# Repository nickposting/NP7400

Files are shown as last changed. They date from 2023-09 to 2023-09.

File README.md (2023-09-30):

# NP7400  

## Processor Card

### Docs
[g4pinout.pdf](/docs/g4pinout.pdf) contains the pinout of the connector used on
Power Mac G4 computers. Some important notes regarding the pinout:

* Pin assignments were determined by first sanding/filing down the processor
card (8 layers) from a 667MHz Digital Audio G4, and then using the card from
a 400MHz AGP Graphics G4, intact, albeit with the processor desoldered,
to verify that all the connections were correct.
* None of the cards involved in this process were dual-processor cards, so any
assignments unique to dual-processor systems, if any exist, have not been 
recorded.
* As written, the pin assignments are representative of how an MPC7450-series
MPU would be interfaced to the Power Mac motherboard -- for instance, only address
bits A4-A35 are present on the connector. Unlike earlier G4 processors, the 7450
features an extended 36-bit address bus, however, the four most significant bits
(A0-A3) are not used in Power Mac systems. Bearing in mind that PowerPC datasheet
conventions specify bit zero as the most-significant bit, a processor card design
featuring an earlier 7400/7410 MPU with a 32-bit address bus would need to have the
MPU's bit A31 connected to the pin labelled "A35" on the pinout, A30 connected to
"A34," and so on. The same applies to the DTI (Data Transaction Index) signals, of
which there are less on MPUs predating the 7450.

Regarding pins marked "special":
* Pins marked "R" are connected only to resistor straps, most of which go to ground.
I am still trying to understand the purpose of most of these. Some straps are
unpopulated on every board in my possession, whereas others vary between boards.
* SDA and SCL are connected only to the SPD I<sup>2</sup>C EEPROM on every board.
* Pins B2 and K30 are connected only to each other on every board. I assume this is
intended for the motherboard to sense whether or not the processor card is fully
seated.
* CKSTP# on the connector is directly connected to both CKSTP_IN# and CKSTP_OUT# on
the MPU.
* D63 is pulled to ground by a 1kΩ resistor on every board for some reason.
* The length of the SYSCLK track in particular is critical (tangentially, it appears
that on cards built for Power Macs with a 167MHz FSB, most track lengths become
tightly controlled).

## VRM

### Docs
[820-1152-A.pdf](/docs/820-1152-A.pdf) contains a poor schematic of the
original VRM board in the Power Mac G4 Cube, drawn only to verify whether or not
there was anything "unusual" about the OEM design (for all intents and purposes,
there isn't).
[np7400_VRM.pdf](/docs/np7400_VRM.pdf) contains the KiCad schematic of the
upgraded VRM board in PDF.

### Schematic and Board Layout
Schematic/layout files are provided as a complete KiCad project. As of the time
of this writing, schematic has been somewhat revised and does not reflect the
older revision of the layout included.

The newer schematic has not been thouroughly proofread. The older layout has not
been tested extensively and should not be used; there is considerable room for
improvement. Most planned changes are regarding optimization of routing, and ease
of assembly.

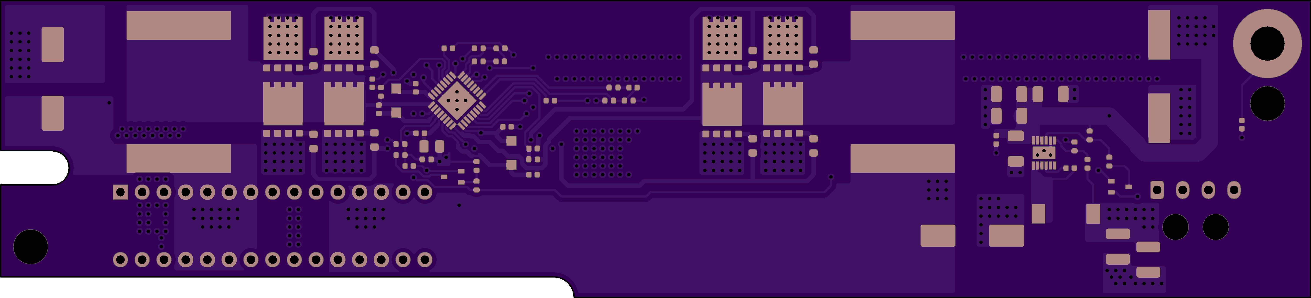
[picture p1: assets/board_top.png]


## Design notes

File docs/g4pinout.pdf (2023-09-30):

R | R-R | R | | DTI1 | QACK# | TA# | PMON_ IN# | DTI3 | TBEN | BG# | QREQ# | TEA# | | DBG# | | D59 | | D55 | | D58 | | | | | | R | | R
+12V | SNS | R | HRESET# | | GBL# | | A7 | | A25 | | A9 | | A17 | | A34 | | A35 | | D56 | | D38 | | D57
SRESET# | SMI# | R | | CI# | | A5 | | A18 | | A26 | | A31 | | A19 | | AACK# | | D60 | | D40 | | D63 | | D29 | | D25 | | D14
FAN1 | CKSTP# | | TSIZ0 | | HIT# | | WT# | | A27 | | A15 | | A30 | | A33 | | A29 | | D33 | | D62 | | D61 | | D24 | | D27 | | D23
INT# | | TSIZ1 | | TT0 | | DTI0 | | A11 | | A22 | | A23 | | A21 | | D34 | | D36 | | D30 | | D28 | | D22 | | D16 | | D10
TDI | TMS | | TBST | | TSIZ2 | | TT1 | | A16 | | A20 | | DTI2 | | D32 | | D35 | | D31 | | D26 | | D21 | | D19 | | D20 | | D15
FAN2 | TRST | | | TT3 | | BR# | | A24 | | A32 | | D37 | | D39 | | D9 | | D13 | | D3 | | D0 | | D17 | | D54 | | D50
| TCK | | | | TT2 | | | | A13 | | A28 | | ARTRY# | | D42 | | D11 | | D41 | | D44 | | D53 | | D5 | | D18 | | D12
| | TDO | | A8 | | A12 | | | | TT4 | | TS | | D8 | | D45 | | D51 | | D46 | | D43 | | D6 | | D49 | | D4 | SDA
| A4 | | A10 | | A14 | | A6 | | SYSCLK | | DRDY# | | D7 | | | | | | D48 | | D47 | | D52 | | D2 | | D1 | SCL | SNS

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
1 | 2 | 3 | 4 | 5 | 6 | 7 | 8 | 9 | 10 | 11 | 12 | 13 | 14 | 15 | 16 | 17 | 18 | 19 | 20 | 21 | 22 | 23 | 24 | 25 | 26 | 27 | 28 | 29 | 30
MPX Bus | GND | +5V | +3V3 | OVdd | Special | No Connect | https://github.com/nickposting/NP7400/

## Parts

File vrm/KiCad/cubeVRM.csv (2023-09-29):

Reference | Quantity | Value | Footprint | Datasheet | Arrow Part Number | Arrow Price/Stock | Description | Height | Manufacturer_Name | Manufacturer_Part_Number | Mouser Part Number | Mouser Price/Stock
C12 | 1 | 100pF | Capacitor_SMD:C_0402_1005Metric | ~
C16 C25 | 2 | 820pF | Capacitor_SMD:C_0402_1005Metric | ~
C18 C24 | 2 | 0.038uF | Capacitor_SMD:C_0402_1005Metric | ~
C2 | 1 | 680uF STANDARD | Capacitor_SMD:CP_Elec_16x17.5 | ~
C21 C23 | 2 | 6800pF | Capacitor_SMD:C_0402_1005Metric | ~
C9 C19 C22 C29 | 4 | 0.47uF | Capacitor_SMD:C_0402_1005Metric | ~
C26 C27 | 2 | 1000pF | Capacitor_SMD:C_0402_1005Metric | ~
C3 | 1 | 1nF | Capacitor_SMD:C_0402_1005Metric | ~
C32 C33 | 2 | 820uF | Capacitor_SMD:CP_Elec_10x10 | ~
C35 C36 C38 C39 C45 C46 | 6 | 22uF | Capacitor_SMD:C_1210_3225Metric | ~
C4 C6 C7 C8 C10 C11 C13 C15 C17 C20 C30 C31 C34 C37 C40 C43 | 16 | 2.2uF | Capacitor_SMD:C_1206_3216Metric | ~
C1 C5 C14 C28 C41 C42 | 6 | 1uF | Capacitor_SMD:C_0402_1005Metric | ~
C47 C50 | 2 | 0.1uF | Capacitor_SMD:C_0402_1005Metric | ~
C44 C48 C49 C51 | 4 | 10uF | Capacitor_SMD:C_1206_3216Metric | ~
D1 D2 | 2 | D_Schottky | Diode_SMD:D_SOD-123F | ~
F1 F2 | 2 | 4A | Fuse:Fuse_1206_3216Metric | ~
H1 H3 | 2 | MountingHole_NP | MountingHole:MountingHole_4mm | ~
H2 | 1 | MountingHole_Pad | MountingHole:MountingHole_4mm_Pad | ~
IC1 | 1 | LM25119QPSQ_NOPB | LM25119QPSQ_NOPB:QFN50P500X500X80-33N | http://www.ti.com/lit/gpn/lm25119q | LM25119QPSQ/NOPB | https://www.arrow.com/en/products/lm25119qpsqnopb/texas-instruments | Switching Controllers Automotive Grade 4.5-42V Wide Vin, Current Mode Dual Synchronous Buck Controller 32-WQFN -40 to 125 | 0.8 | Texas Instruments | LM25119QPSQ/NOPB | 595-LM25119QPSQ/NOPB | https://www.mouser.com/Search/Refine.aspx?Keyword=595-LM25119QPSQ%2FNOPB
IC2 | 1 | LMR51450FNDRRR | LMR51450FNDRRR:SON50P300X300X80-13N-D | https://www.ti.com/lit/ds/symlink/lmr51450.pdf?ts=1681907573404 | LMR51450FNDRRR | https://www.arrow.com/en/products/lmr51450fndrrr/texas-instruments?region=nac | Switching Voltage Regulators 36-V, 5-A synchronous buck converter | 0.8 | Texas Instruments | LMR51450FNDRRR | 595-LMR51450FNDRRR | https://www.mouser.co.uk/ProductDetail/Texas-Instruments/LMR51450FNDRRR?qs=rQFj71Wb1eVWWBj0Ni4OAA%3D%3D
J1 | 1 | Conn_01x04 | Connector_Molex:Molex_Micro-Fit_3.0_43650-0400_1x04_P3.00mm_Horizontal | ~
J2 | 1 | Conn_02x15_Odd_Even | Connector_PinHeader_2.54mm:PinHeader_2x15_P2.54mm_Vertical | ~
L1 | 1 | 8.2uH | SRP1770TA-5R6M:INDPM173169X700N | ~
L2 | 1 | 5.6uH | SRP1770TA-5R6M:INDPM173169X700N | ~
L3 | 1 | 6.8uH | Inductor_SMD:L_7.3x7.3_H4.5 | ~
Q1 Q10 | 2 | 2N3904 | Package_TO_SOT_SMD:SOT-323_SC-70 | https://www.onsemi.com/pub/Collateral/2N3903-D.PDF
Q2 Q3 Q4 Q5 Q6 Q7 Q8 Q9 | 8 | Q_NMOS_DGS | Package_SON:VSONP-8-1EP_5x6_P1.27mm | ~
R10 | 1 | 3.9R | Resistor_SMD:R_0805_2012Metric | ~
R11 | 1 | 24.9k | Resistor_SMD:R_0402_1005Metric | ~
R12 | 1 | 20.5k | Resistor_SMD:R_0402_1005Metric | ~
R13 R14 R15 R16 R24 R25 R26 R27 | 8 | 10R | Resistor_SMD:R_0603_1608Metric | ~
R17 | 1 | 3.92k | Resistor_SMD:R_0402_1005Metric | ~
R18 | 1 | 1.24k | Resistor_SMD:R_0402_1005Metric | ~
R19 | 1 | 84.5k | Resistor_SMD:R_0402_1005Metric | ~
R2 R30 R34 | 3 | 100R | Resistor_SMD:R_0402_1005Metric | ~
R20 R21 R28 R29 | 4 | 10R | Resistor_SMD:R_0402_1005Metric | ~
R22 R23 | 2 | 0R005 | Resistor_SMD:R_2512_6332Metric | ~
R3 | 1 | 47R | Resistor_SMD:R_0402_1005Metric | ~
R1 R31 R32 R35 | 4 | 100k | Resistor_SMD:R_0402_1005Metric | ~
R33 | 1 | 7.15k | Resistor_SMD:R_0402_1005Metric | ~
R4 | 1 | 52.3k | Resistor_SMD:R_0402_1005Metric | ~
R5 | 1 | 3k | Resistor_SMD:R_0402_1005Metric | ~
R6 | 1 | 5.76k | Resistor_SMD:R_0402_1005Metric | ~
R7 | 1 | 1.1k | Resistor_SMD:R_0402_1005Metric | ~
R8 | 1 | 124k | Resistor_SMD:R_0402_1005Metric | ~
R9 | 1 | 30k | Resistor_SMD:R_0402_1005Metric | ~

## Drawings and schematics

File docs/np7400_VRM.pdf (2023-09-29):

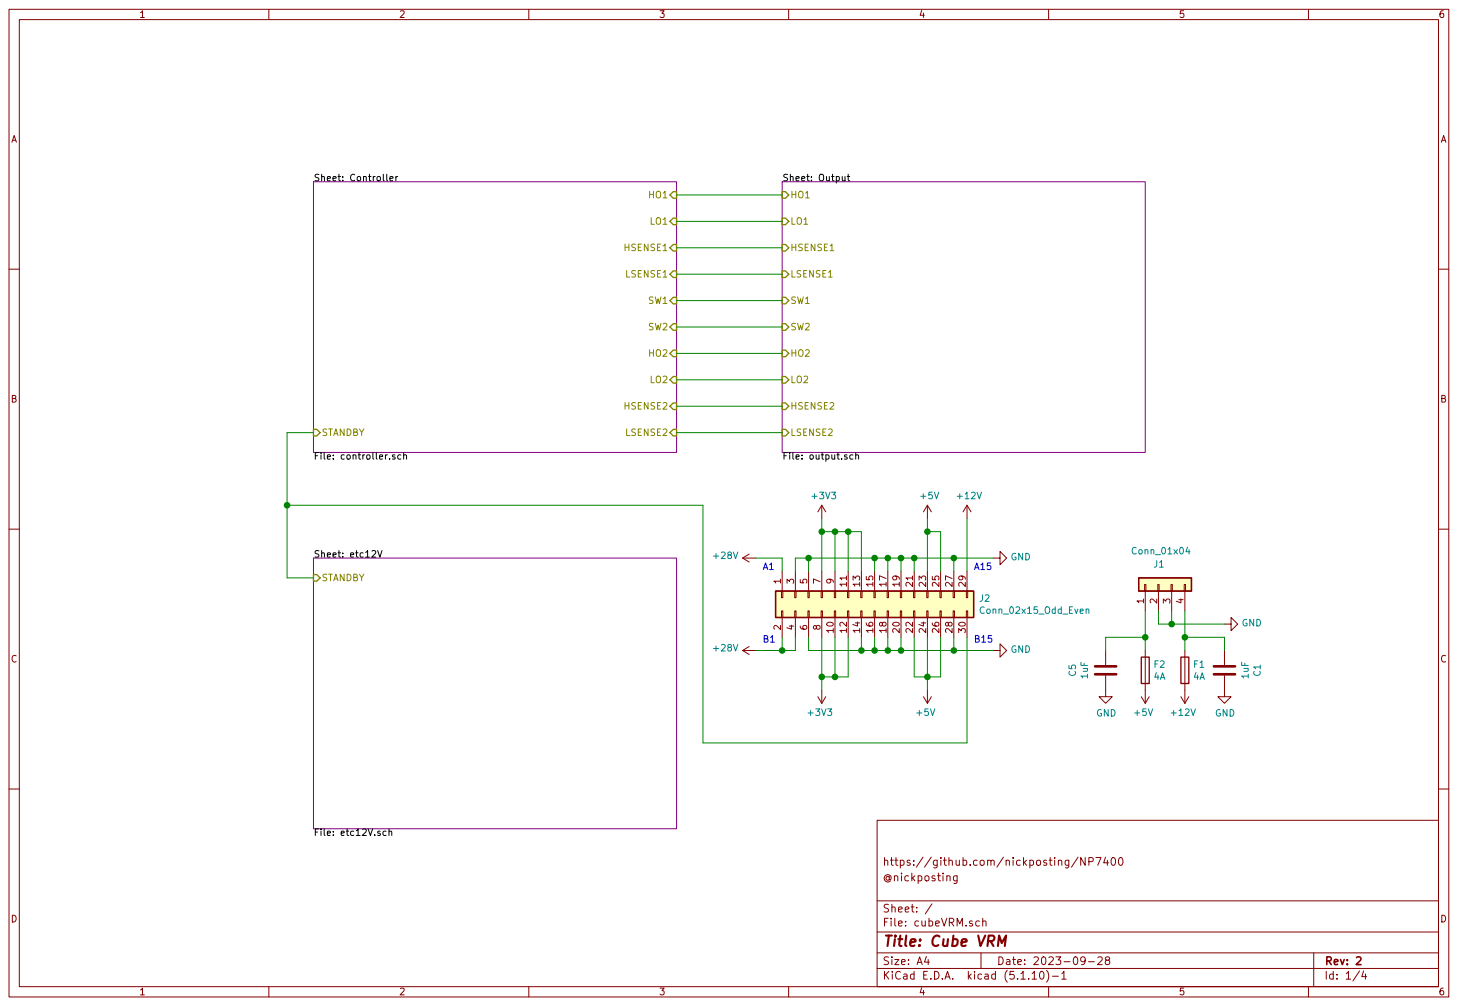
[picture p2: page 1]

https://github.com/nickposting/NP7400
File: cubeVRM.sch Sheet: / @nickposting

Id: 1/4 Title: Cube VRM

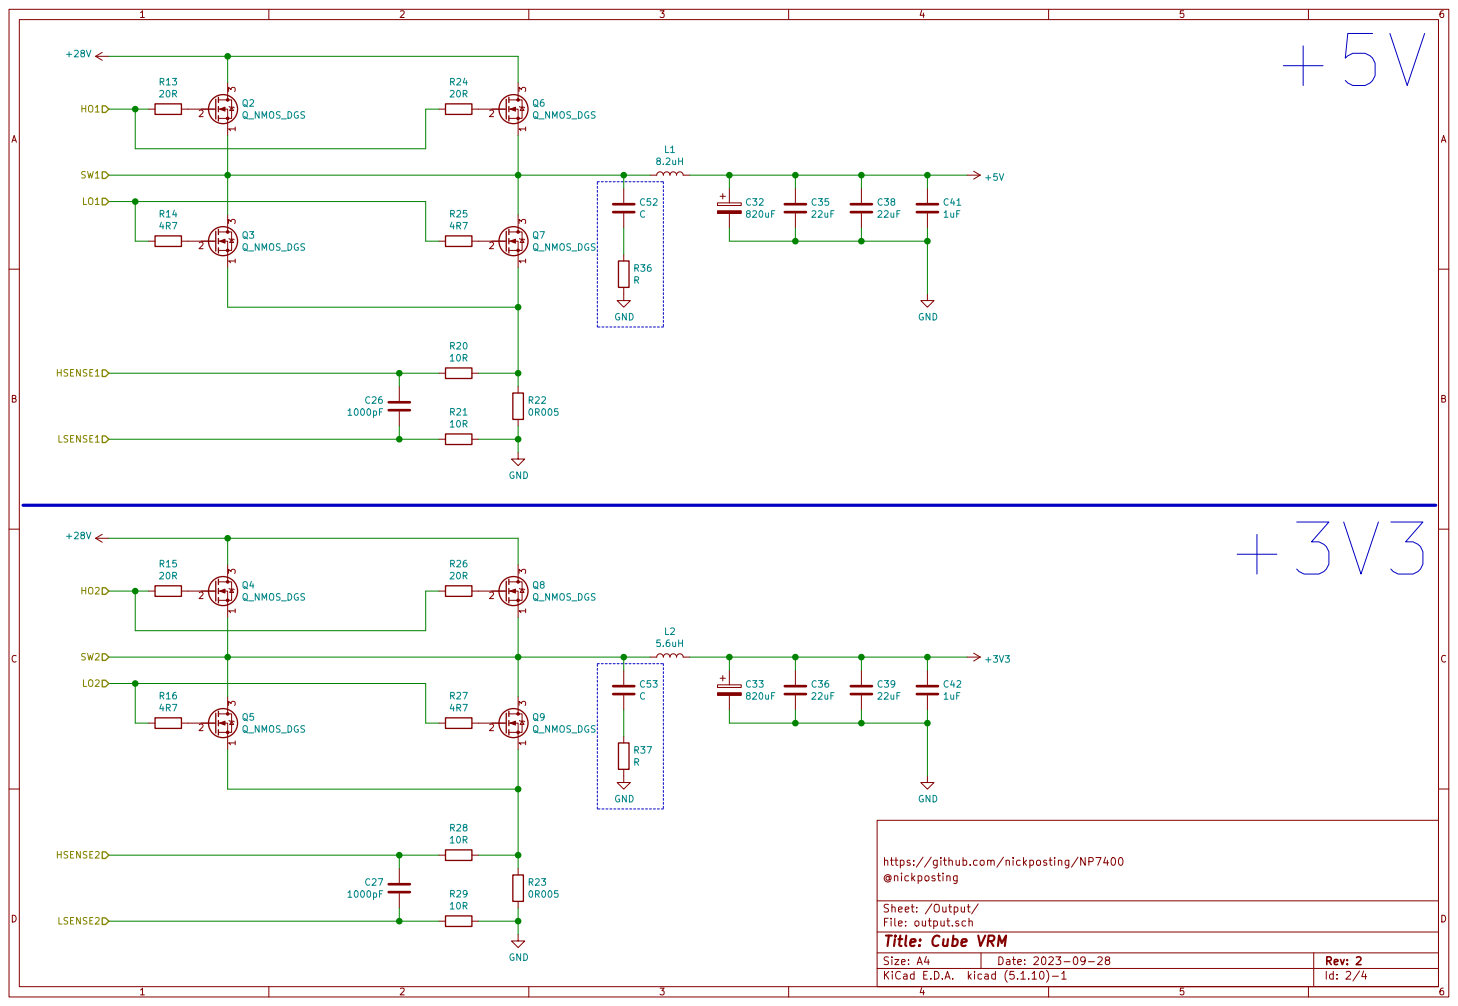
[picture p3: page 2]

https://github.com/nickposting/NP7400 GND

Sheet: /Output/
File: output.sch
Id: 2/4 Title: Cube VRM

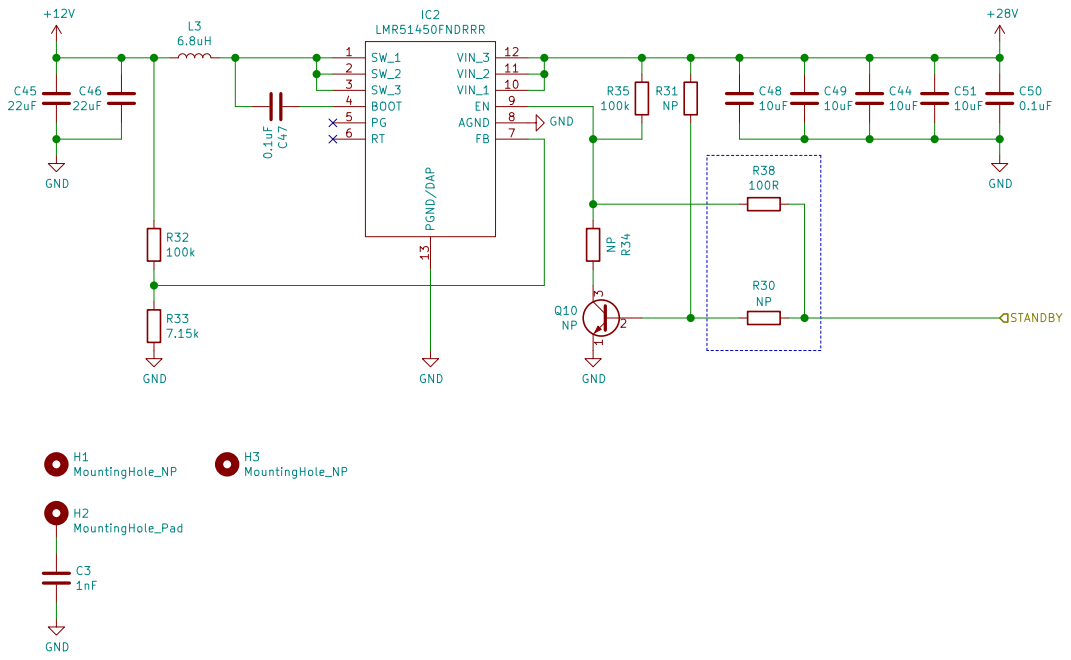
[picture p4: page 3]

3 Q10 NP GND NP R34 R30 NP R31 NP GND

https://github.com/nickposting/NP7400
File: etc12V.sch Sheet: /etc12V/ @nickposting

Id: 3/4 Title: Cube VRM

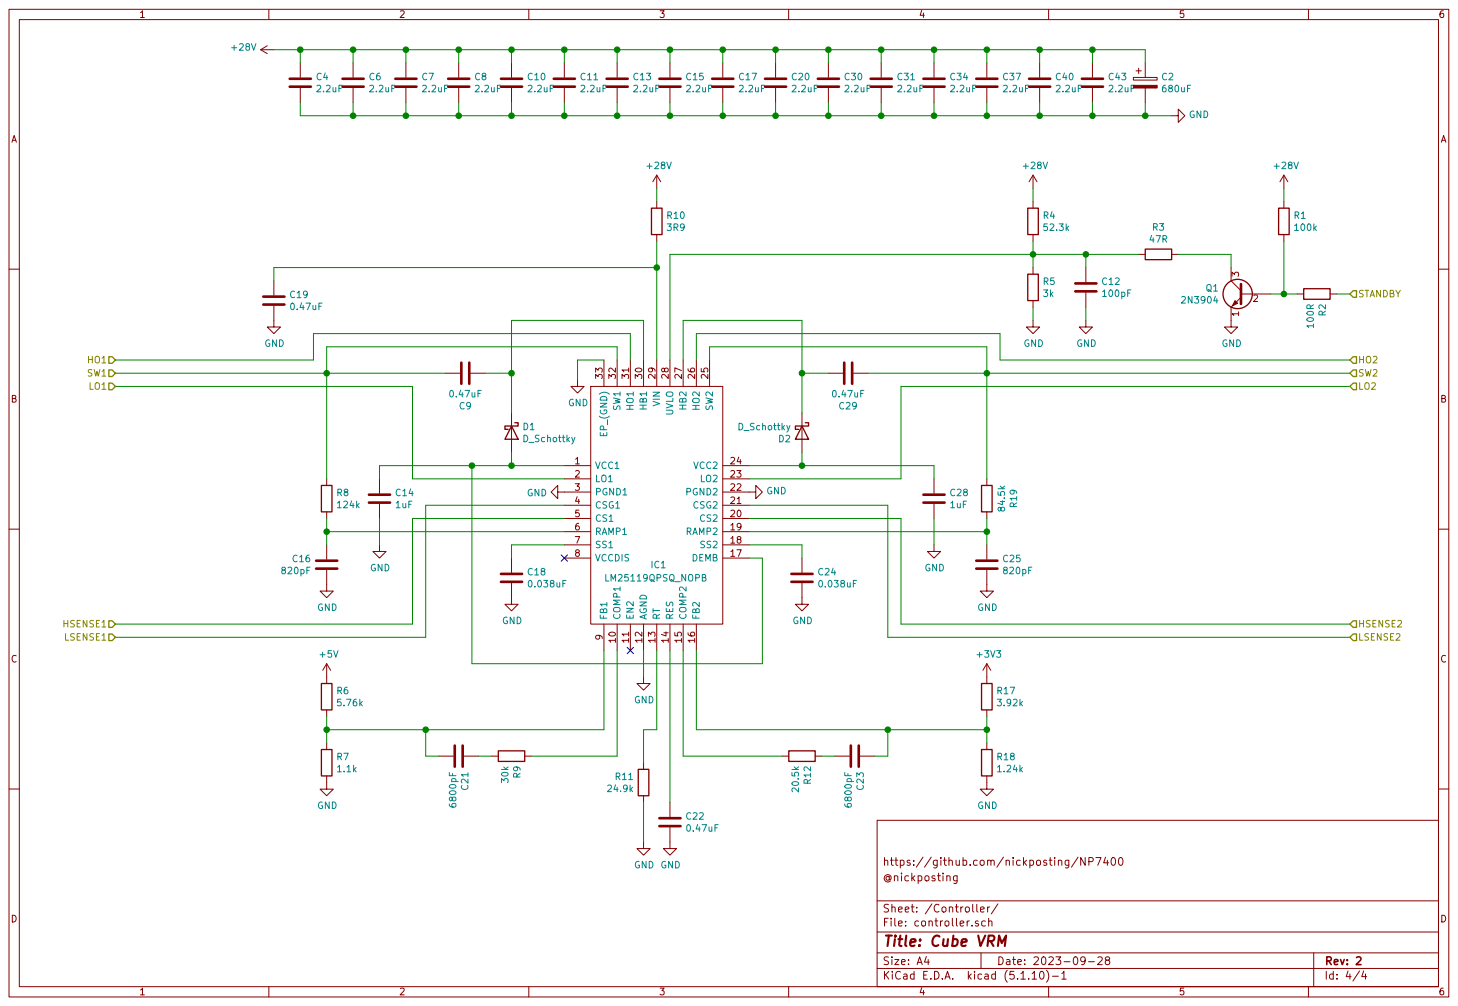
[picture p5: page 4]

File: controller.sch Sheet: /Controller/ @nickposting

Id: 4/4 Title: Cube VRM

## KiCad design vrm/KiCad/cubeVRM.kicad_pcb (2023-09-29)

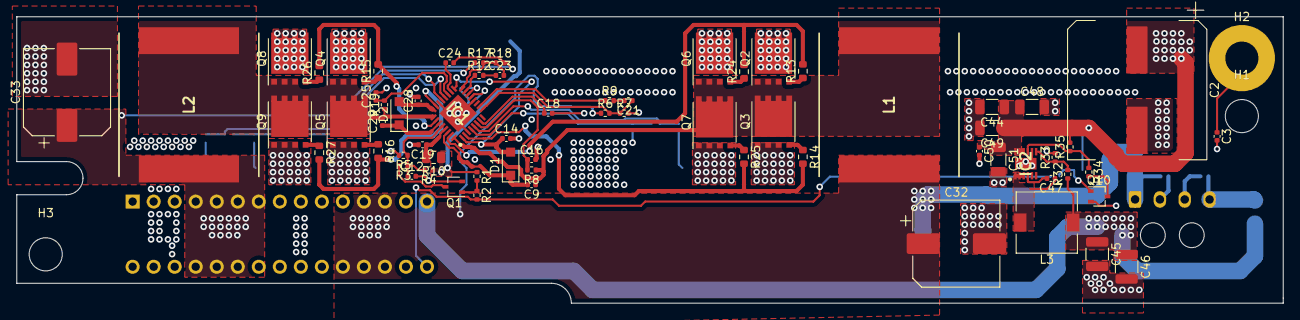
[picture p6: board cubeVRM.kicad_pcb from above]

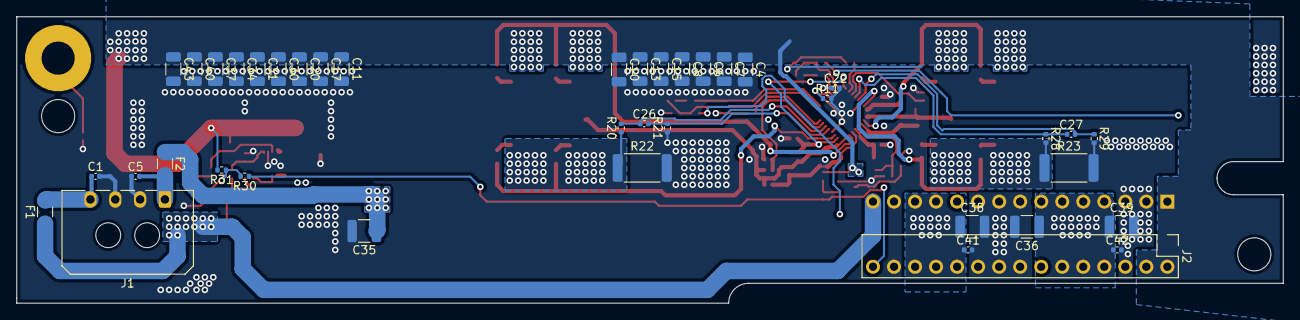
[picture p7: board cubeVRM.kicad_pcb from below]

Board: 4 copper layers, 153.0 x 34.6 mm, 110 parts (40 on the bottom side), 55 nets.

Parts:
C1, C5, C14, C28, C41, C42: 1uF; C_0402_1005Metric
C2: 680uF STANDARD; CP_Elec_16x17.5
C3: 1nF; C_0402_1005Metric
C4, C6, C7, C8, C10, C11, C13, C15, C17, C20, C30, C31, C34, C37, C40, C43: 2.2uF; C_1206_3216Metric
C9, C19, C22, C29: 0.47uF; C_0402_1005Metric
C12: 100pF; C_0402_1005Metric
C16, C25: 820pF; C_0402_1005Metric
C18, C24: 0.038uF; C_0402_1005Metric
C21, C23: 6800pF; C_0402_1005Metric
C26, C27: 1000pF; C_0402_1005Metric
C32, C33: 820uF; CP_Elec_10x10
C35, C36, C38, C39, C45, C46: 22uF; C_1210_3225Metric
C44, C48, C49, C51: 10uF; C_1206_3216Metric
C47, C50: 0.1uF; C_0402_1005Metric
D1, D2: D_Schottky; D_SOD-123F
F1, F2: 4A; Fuse_1206_3216Metric
H1, H3: MountingHole_NP; MountingHole_4mm
H2: MountingHole_Pad; MountingHole_4mm_Pad
IC1: LM25119QPSQ_NOPB; QFN50P500X500X80-33N
IC2: LMR51450FNDRRR; SON50P300X300X80-13N-D
J1: Conn_01x04; Molex_Micro-Fit_3.0_43650-0400_1x04_P3.00mm_Horizontal
J2: Conn_02x15_Odd_Even; PinHeader_2x15_P2.54mm_Vertical
L1: 8.2uH; INDPM173169X700N
L2: 5.6uH; INDPM173169X700N
L3: 6.8uH; L_7.3x7.3_H4.5
Q1, Q10: 2N3904; SOT-323_SC-70
Q2, Q3, Q4, Q5, Q6, Q7, Q8, Q9: Q_NMOS_DGS; VSONP-8-1EP_5x6_P1.27mm
R1, R31, R32, R35: 100k; R_0402_1005Metric
R2, R30, R34: 100R; R_0402_1005Metric
R3: 47R; R_0402_1005Metric
R4: 52.3k; R_0402_1005Metric
R5: 3k; R_0402_1005Metric
R6: 5.76k; R_0402_1005Metric
R7: 1.1k; R_0402_1005Metric
R8: 124k; R_0402_1005Metric
R9: 30k; R_0402_1005Metric
R10: 3.9R; R_0805_2012Metric
R11: 24.9k; R_0402_1005Metric
R12: 20.5k; R_0402_1005Metric
R13, R14, R15, R16, R24, R25, R26, R27: 10R; R_0603_1608Metric
R17: 3.92k; R_0402_1005Metric
R18: 1.24k; R_0402_1005Metric
R19: 84.5k; R_0402_1005Metric
R20, R21, R28, R29: 10R; R_0402_1005Metric
R22, R23: 0R005; R_2512_6332Metric
R33: 7.15k; R_0402_1005Metric

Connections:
28VDC: C2.1, C4.1, C6.1, C7.1, C8.1, C10.1, C11.1, C13.1, C15.1, C17.1, C20.1, C30.1, C31.1, C34.1, C37.1, C40.1, C43.1, C44.1, C48.1, C49.1, C50.1, C51.1, IC2.10, IC2.11, IC2.12, J2.1, J2.2, J2.4, Q2.3, Q4.3, Q6.3, Q8.3, R1.1, R4.1, R10.1, R31.2, R35.2
+3V3: C33.1, C36.1, C39.1, C42.1, J2.7, J2.8, J2.9, J2.10, J2.11, J2.12, J2.13, L2.2, R17.1
+5V: C32.1, C35.1, C38.1, C41.1, F2.1, J2.22, J2.23, J2.24, J2.25, J2.26, L1.2, R6.1
+12V: C45.1, C46.1, F1.1, J2.29, L3.1, R32.1
GND: C1.2, C2.2, C3.2, C4.2, C5.1, C6.2, C7.2, C8.2, C10.2, C11.2, C12.2, C13.2, C14.2, C15.2, C16.2, C17.2, C18.2, C19.2, C20.2, C22.2, C24.2, C25.2, C28.2, C30.2, C31.2, C32.2, C33.2, C34.2, C35.2, C36.2, C37.2, C38.2, C39.2, C40.2, C41.2, C42.2, C43.2, C44.2, C45.2, C46.2, C48.2, C49.2, C50.2, C51.2, IC1.3, IC1.12, IC1.22, IC1.33, IC2.8, IC2.13, J1.2, J1.3, J2.3, J2.5, J2.6, J2.14, J2.15, J2.16, J2.17, J2.18, J2.19, J2.20, J2.21, J2.27, J2.28, Q1.1, Q10.1, R5.2, R7.2, R11.2, R18.2, R21.1, R22.2, R23.2, R29.2, R33.2
HB1: C9.2, D1.1, IC1.30
HB2: C29.1, D2.1, IC1.27
unnamed: C1.1, F1.2, J1.4
unnamed: C3.1, H2.1
unnamed: C5.2, F2.2, J1.1
unnamed: C9.1, IC1.32, L1.1, Q2.1, Q3.3, Q6.1, Q7.3, R8.1
unnamed: C12.1, IC1.28, R3.1, R4.2, R5.1
unnamed: C14.1, D1.2, IC1.1, IC1.17
unnamed: C16.1, IC1.6, R8.2
unnamed: C18.1, IC1.7
unnamed: C19.1, IC1.29, R10.2
unnamed: C21.1, IC1.9, R6.2, R7.1
unnamed: C21.2, R9.2
unnamed: C22.1, IC1.14
unnamed: C23.1, R12.2
unnamed: C23.2, IC1.16, R17.2, R18.1
unnamed: C24.1, IC1.18
unnamed: C25.1, IC1.19, R19.2
unnamed: C26.1, IC1.5, R20.2
unnamed: C26.2, IC1.4, R21.2
unnamed: C27.1, IC1.20, R28.1
unnamed: C27.2, IC1.21, R29.1
unnamed: C28.1, D2.2, IC1.24
unnamed: C29.2, IC1.25, L2.1, Q4.1, Q5.3, Q8.1, Q9.3, R19.1
unnamed: C47.1, IC2.1, IC2.2, IC2.3, L3.2
unnamed: C47.2, IC2.4
unnamed: IC1.2, R14.2, R25.2
unnamed: IC1.10, R9.1
unnamed: IC1.13, R11.1
unnamed: IC1.15, R12.1
unnamed: IC1.23, R16.2, R27.2
unnamed: IC1.26, R15.2, R26.2
unnamed: IC1.31, R13.2, R24.2
unnamed: IC2.7, R32.2, R33.1
unnamed: IC2.9, R34.1, R35.1
unnamed: Q1.2, R1.2, R2.1
unnamed: Q1.3, R3.2
unnamed: Q2.2, R13.1
unnamed: Q3.1, Q7.1, R20.1, R22.1
unnamed: Q3.2, R14.1
unnamed: Q4.2, R15.1
unnamed: Q5.1, Q9.1, R23.1, R28.2
unnamed: Q5.2, R16.1
unnamed: Q6.2, R24.1
unnamed: Q7.2, R25.1
unnamed: Q8.2, R26.1
unnamed: Q9.2, R27.1
unnamed: Q10.2, R30.2, R31.1
unnamed: Q10.3, R34.2
STANDBY: J2.30, R2.2, R30.1

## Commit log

2023-09-29 Add schematics, layout files
    Revising schematic, does not match layout (rev1) or netlist yet. Strongly recommend against using rev1 board layout; still in dire need of optimization
    [SP12V.sch, controller.sch, cubeVRM.csv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]
2023-09-30 Move VRM design files, add processor card pinout and notes
    [SP12V.sch, controller.sch, cubeVRM.csv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]
